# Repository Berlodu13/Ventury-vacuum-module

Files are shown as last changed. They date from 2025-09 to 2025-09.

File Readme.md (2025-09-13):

# Module Venturi imprimable pour purge de freins et aspiration de fluides

Ce projet open-source propose un générateur de vide basé sur l’effet Venturi, conçu pour être imprimé en 3D et utilisé avec un compresseur standard. Il permet de purger des circuits de frein, aspirer des liquides ou créer un petit aspirateur d’atelier.

## 🔧 Fonctionnalités
- Compatible avec compresseur 6–8 bar
- Buses interchangeables (M6)
- Port vacuomètre intégré
- Capot d’échappement silencé
- Bocal séparateur en verre ou imprimé
- Fichiers STEP et STL fournis
- Script Python paramétrique (CadQuery)

## 🧱 Matériaux recommandés
- ASA (résistance chimique et thermique)
- PETG CF ou ABS pour prototype
- Joints FKM/Viton pour fluides DOT ou huile

## 🖨️ Impression
- 5 périmètres, 80–100% infill
- Hauteur de couche 0.2 mm
- Supports activés sous les perçages horizontaux
- Orientation verticale pour le corps principal

## 🛠️ Montage
- Taraudages : 1/4" BSP (air, vide), 1/8" NPT (vacuomètre), M6 (buse)
- Raccords rapides standard
- Clapet anti-retour recommandé
- Bocal séparateur en verre (type conserve) avec déflecteur

## 🧪 Tests
- Dépression obtenue : -65 kPa avec buse Ø 2.0 mm
- Débit d’aspiration : ~10 L/min
- Compatible purge de freins, aspiration d’huile, nettoyage

## 📁 Structure du dépôt

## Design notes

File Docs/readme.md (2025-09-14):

Module opp:
# 🛠️ Notice de montage — Module Venturi imprimable

## 📦 Pièces nécessaires
- Corps venturi imprimé (ASA, PETG CF, PETG ou ABS)
- Porte-buse M6
- Capot échappement silencé
- Buse M6 Ø 2.0 mm
- Vacuomètre 1/8" NPT
- Raccord rapide 1/4" BSP
- Barb 1/4" BSP → tuyau 6–8 mm
- Clapet anti-retour
- Bocal séparateur (verre type conserve 500–750 mL)
- Tuyau silicone 6×9 mm

## 🧩 Composition de la pièce
Ta pièce se compose de trois éléments principaux :

1. Corps Venturi

C’est le tube central qui crée la dépression.
Il a une entrée large, un rétrécissement interne (effet Venturi), et une sortie.

2. Embout MIG (entrée d’air comprimé)
Se fixe à la base du corps Venturi.
Permet de connecter un compresseur via une buse MIG ou un raccord rapide.

3. Embout M6 (aspiration)
Se visse ou s’emboîte à l’autre extrémité.
Sert à raccorder un tuyau pour aspirer liquide de frein, huile, etc.

## 🧰 Étapes de montage

1. **Impression des pièces**
- Imprime les 3 éléments séparément : corps, embout_mig, embout_m6.
- Matériau recommandé : ASA, PETG CF, PETG ou ABS (résistant aux fluides et à la chaleur).
- Remplissage : 40–50% pour la solidité.

2. **Préparation**
   - Ébavurer les pièces imprimées
   - Tarauder :
     - Entrée air : 1/4" BSP
     - Sortie vide : 1/4" BSP
     - Vacuomètre : 1/8" NPT
     - Porte-buse : M6

2. **Assemblage**
   - Fixation des embouts
      - Embout MIG :
         - S’insère à la base du corps (côté entrée d’air).
         - Tu peux le coller, visser ou utiliser un joint torique pour l’étanchéité.
      - Embout M6 :
         - Se visse à l’autre extrémité.
         - Tu peux y insérer une buse d’imprimante 3D ou un tuyau souple.
   - Visser la buse M6 dans le porte-buse
   - Insérer le porte-buse dans le corps venturi
   - Visser le raccord rapide sur l’entrée air
   - Visser le barb sur la sortie vide
   - Visser le vacuomètre sur le bossage supérieur
   - Monter le capot échappement ou silencieux

4. **Bocal séparateur**
   - Percer le couvercle : 2 × Ø 12 mm
   - Monter les passe-cloisons 1/4" BSP
   - Ajouter un déflecteur sous le tube plongeur
   - Connecter :
     - IN : venturi → bocal (tube plongeur)
     - OUT : bocal → purgeur (tube haut)

5. **Branchement**
   -Branche ton compresseur à l’embout MIG.
   - Pression recommandée : 4 à 6 bars.
   - Compresseur → venturi (raccord rapide)
   - Raccorde un tuyau souple à l’embout M6.
   - Plonge l’autre extrémité du tuyau dans le liquide à aspirer.
   - Quand l’air circule, l’effet Venturi crée une dépression qui aspire le fluide.
   - Venturi → bocal → purgeur
   - Vacuomètre sur le bossage

6. **Test**
   - Mettre en pression (6–7 bar)
   - Observer le vacuomètre

   - Vérifier l’aspiration et l’étanchéité

##  🧪 Astuces d’atelier
- Tu peux ajouter un clapet anti-retour entre l embout M6 et le tuyau pour éviter les reflux.
- Si tu veux aspirer des liquides visqueux (huile moteur), augmente légèrement le diamètre du conduit.
- Pour un usage en atelier, tu peux fixer le module sur un support ou une plaque murale.

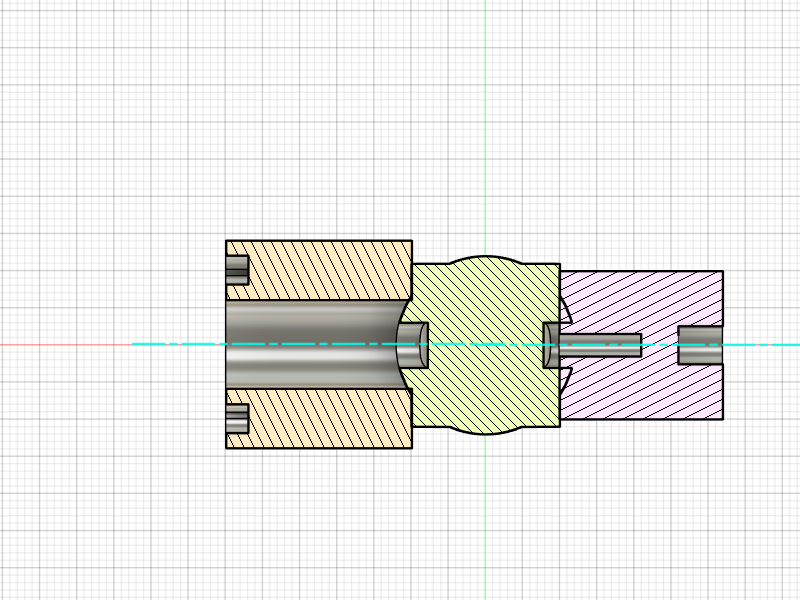
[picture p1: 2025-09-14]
Docs/vue en coupe bas.png

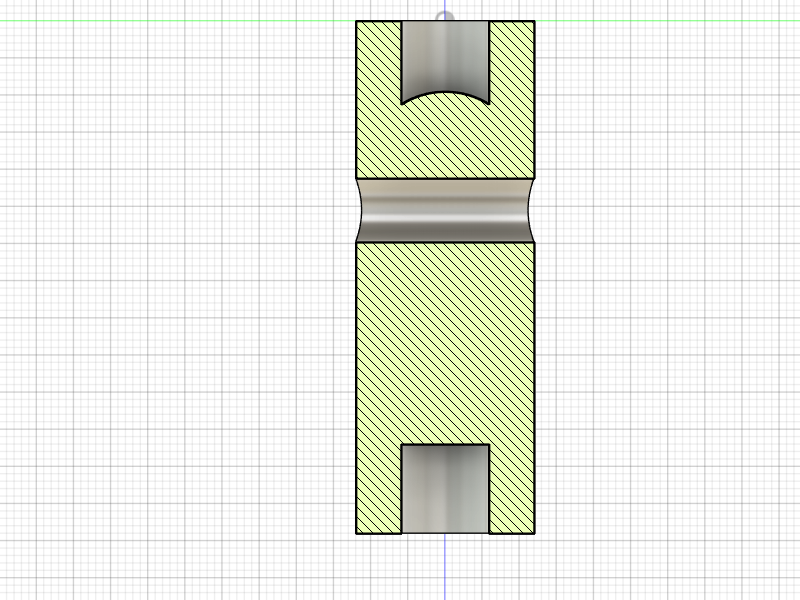
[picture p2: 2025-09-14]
Docs/vue en coupe 2.png

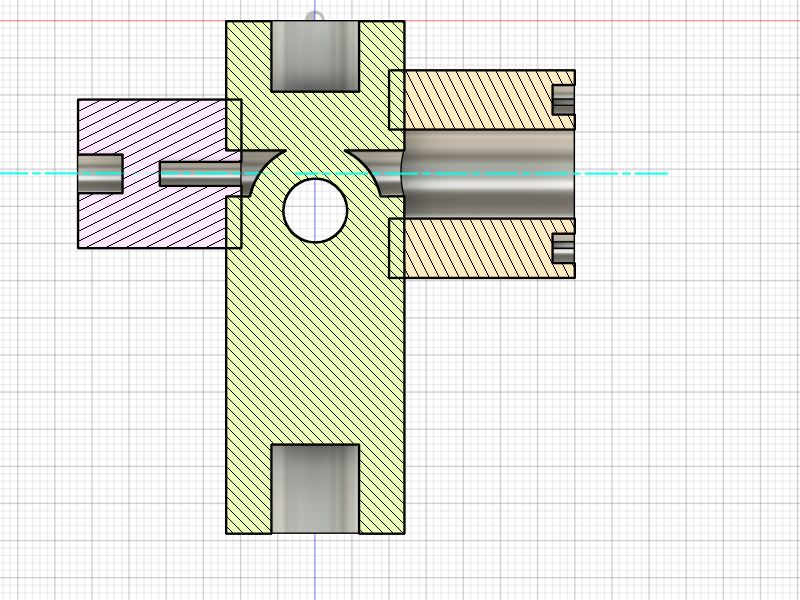
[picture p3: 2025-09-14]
Docs/vue en coupe.png

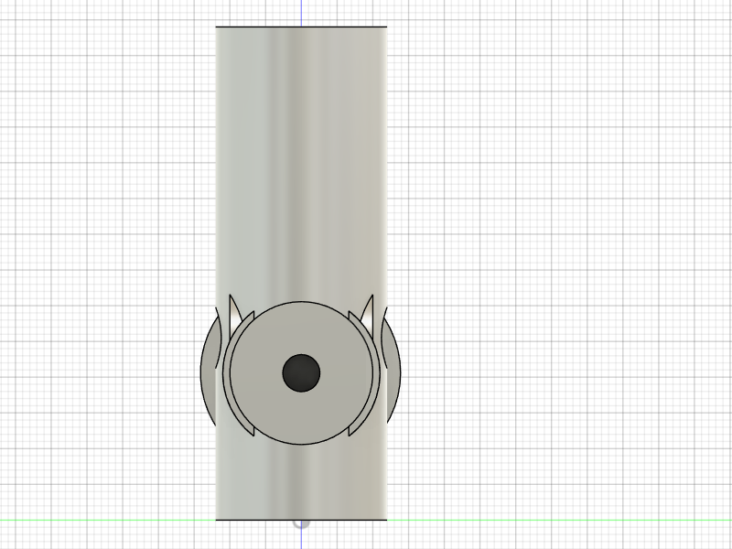
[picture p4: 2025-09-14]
Docs/vue de gauche.png

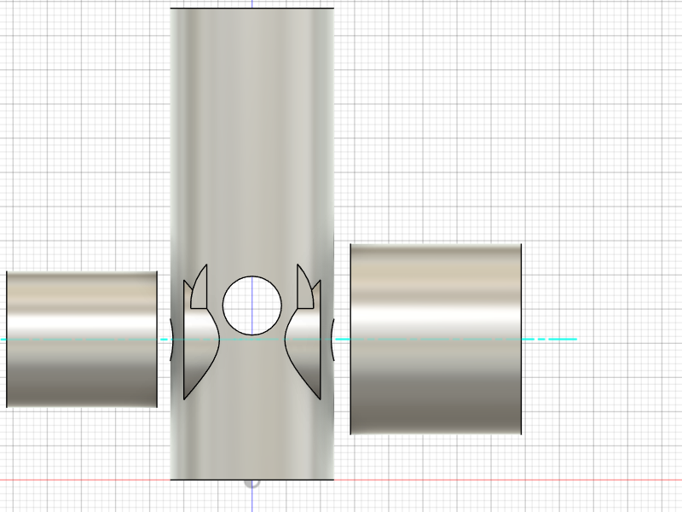
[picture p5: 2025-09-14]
Docs/vue éclaté.png

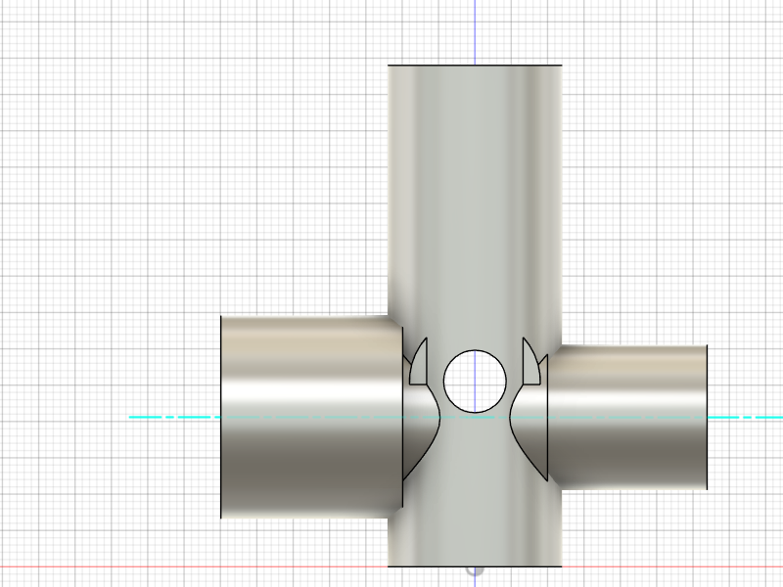
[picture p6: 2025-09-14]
Docs/vue de face.png

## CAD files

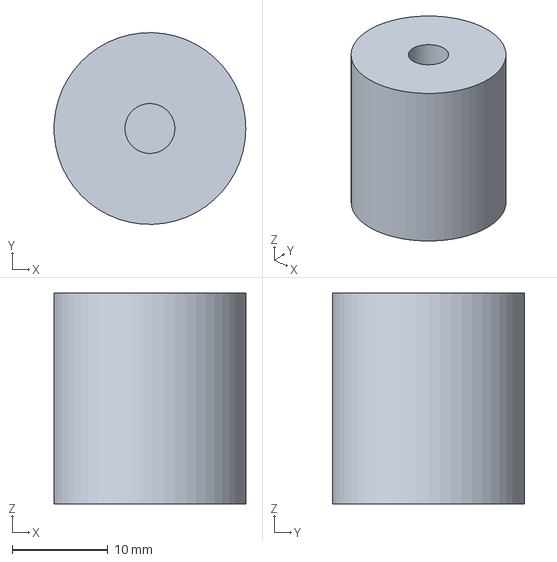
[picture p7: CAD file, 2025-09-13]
Cad/nozzle_holder_v2.step
20.0 x 20.0 x 22.0 mm

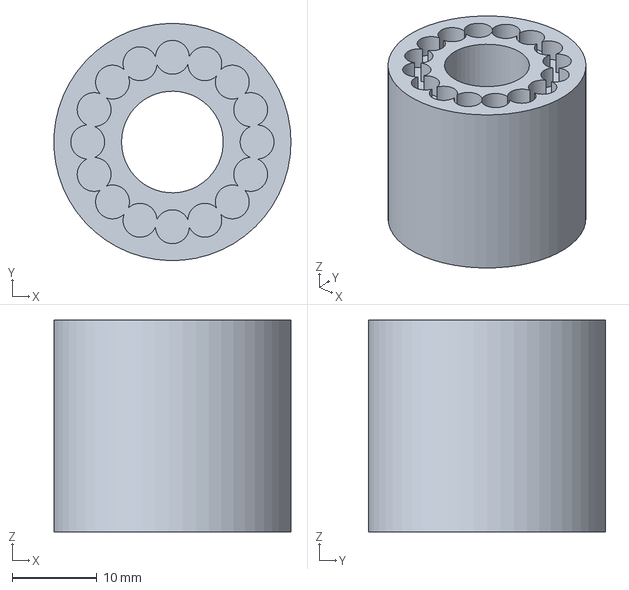
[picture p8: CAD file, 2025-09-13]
Cad/exhaust_cap_v2.step
28.0 x 28.0 x 25.0 mm

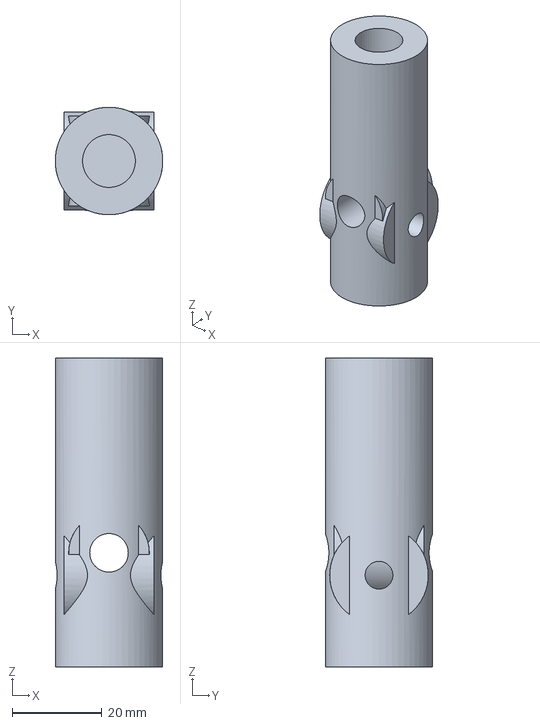
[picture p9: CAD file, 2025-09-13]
Cad/venturi_body_v2.step
24.0 x 24.0 x 69.0 mm

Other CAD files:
Cad/nozzle_holder.step
Cad/venturi_body.step
Cad/exhaust_cap.step
STL/Exhaust_cap.stl
STL/Nozzle_holder.stl
STL/Venturi_body.stl
STL/exhaust_cap_v2.stl
STL/nozzle_holder_v2.stl
STL/venturi_body_v2.stl

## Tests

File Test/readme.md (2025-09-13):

Module opp:
# 🛠️ Notice de montage — Module Venturi imprimable

## 📦 Pièces nécessaires
- Corps venturi imprimé (ASA ou PETG CF)
- Porte-buse M6
- Capot échappement silencé
- Buse M6 Ø 2.0 mm
- Vacuomètre 1/8" NPT
- Raccord rapide 1/4" BSP
- Barb 1/4" BSP → tuyau 6–8 mm
- Clapet anti-retour
- Bocal séparateur (verre type conserve 500–750 mL)
- Tuyau silicone 6×9 mm

## 🧰 Étapes de montage

1. **Préparation**
   - Ébavurer les pièces imprimées
   - Tarauder :
     - Entrée air : 1/4" BSP
     - Sortie vide : 1/4" BSP
     - Vacuomètre : 1/8" NPT
     - Porte-buse : M6

2. **Assemblage**
   - Visser la buse M6 dans le porte-buse
   - Insérer le porte-buse dans le corps venturi
   - Visser le raccord rapide sur l’entrée air
   - Visser le barb sur la sortie vide
   - Visser le vacuomètre sur le bossage supérieur
   - Monter le capot échappement ou silencieux

3. **Bocal séparateur**
   - Percer le couvercle : 2 × Ø 12 mm
   - Monter les passe-cloisons 1/4" BSP
   - Ajouter un déflecteur sous le tube plongeur
   - Connecter :
     - IN : venturi → bocal (tube plongeur)
     - OUT : bocal → purgeur (tube haut)

4. **Branchement**
   - Compresseur → venturi (raccord rapide)
   - Venturi → bocal → purgeur
   - Vacuomètre sur le bossage

5. **Test**
   - Mettre en pression (6–7 bar)
   - Observer le vacuomètre
   - Vérifier l’aspiration et l’étanchéité
